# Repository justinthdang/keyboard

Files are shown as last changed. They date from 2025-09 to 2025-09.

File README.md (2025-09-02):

# 60% Mechancial Keyboard PCB
This repository showcases a 61-switch mechanical keyboard PCB made in Altium Designer for DFM with JLCPCB. The board is powered by a Raspberry Pi RP2040 chip on a 6-layer SIG-GND-PWR-SIG-GND-SIG stack up and follows the standard [GH60](https://github.com/komar007/gh60) layout + sizing for modern 60% mechanical keyboard cases. It features per-key RGB LED lighting, hot-swap sockets for MX-style switches, USB-C power & ESD protection, as well as support for UART, SWD, and UF2 bootloading. 

## Schematic
### Main Components
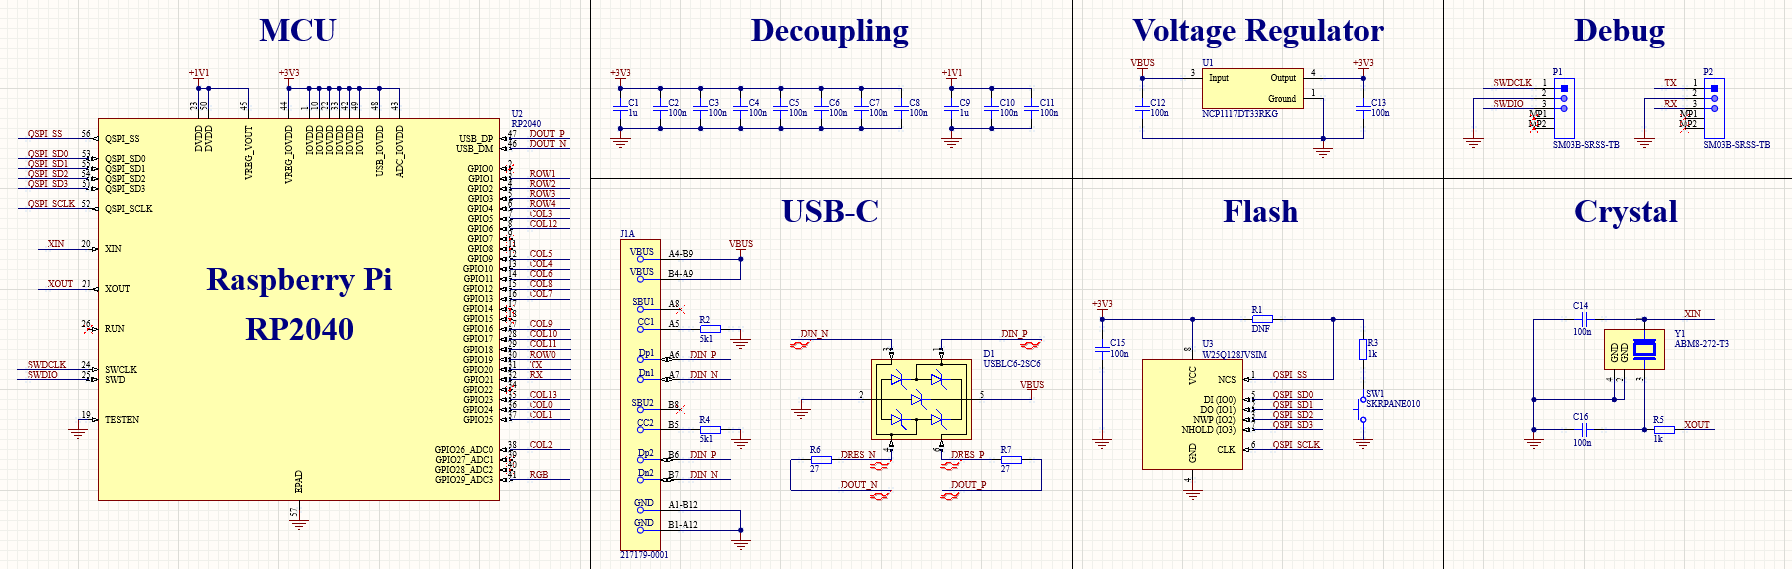
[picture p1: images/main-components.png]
Main Components Schematic

### Switch Matrix
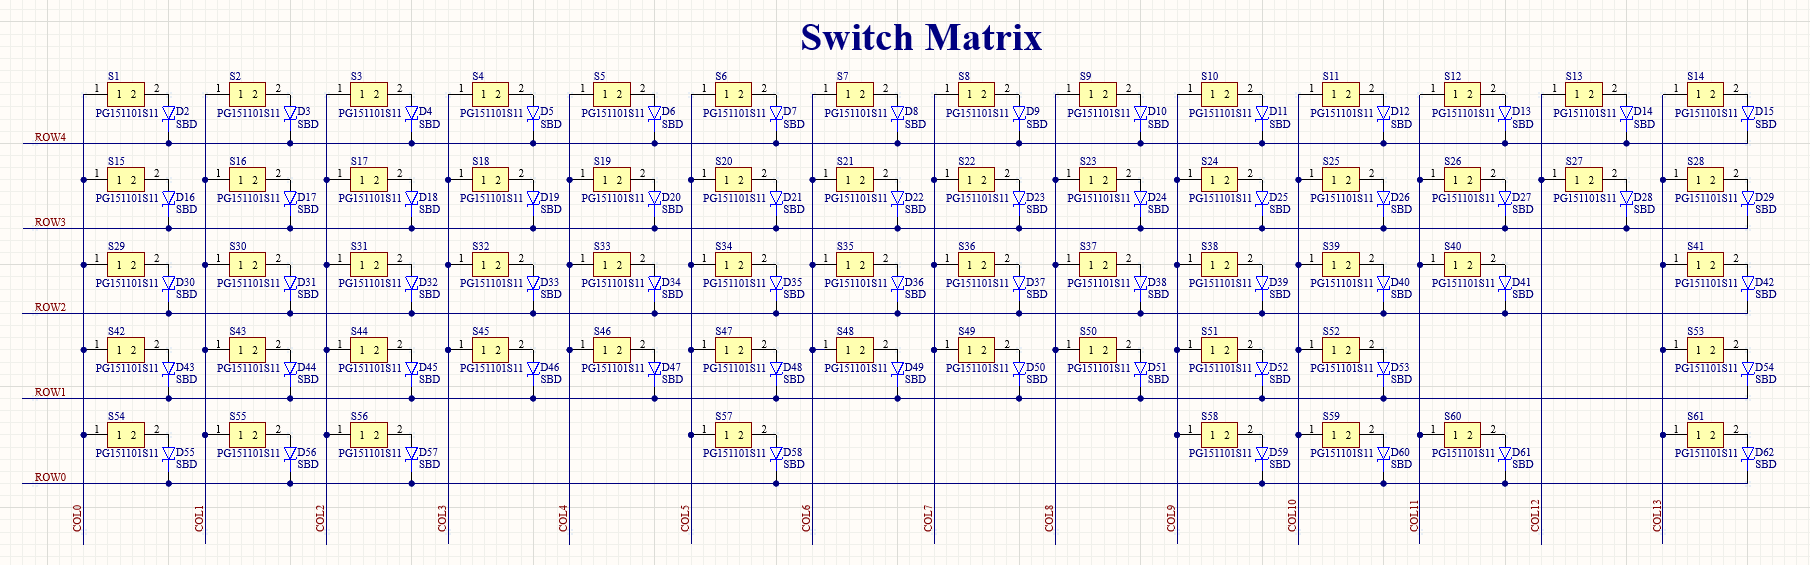
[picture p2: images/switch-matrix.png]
Switch Matrix Schematic

### RGB Matrix
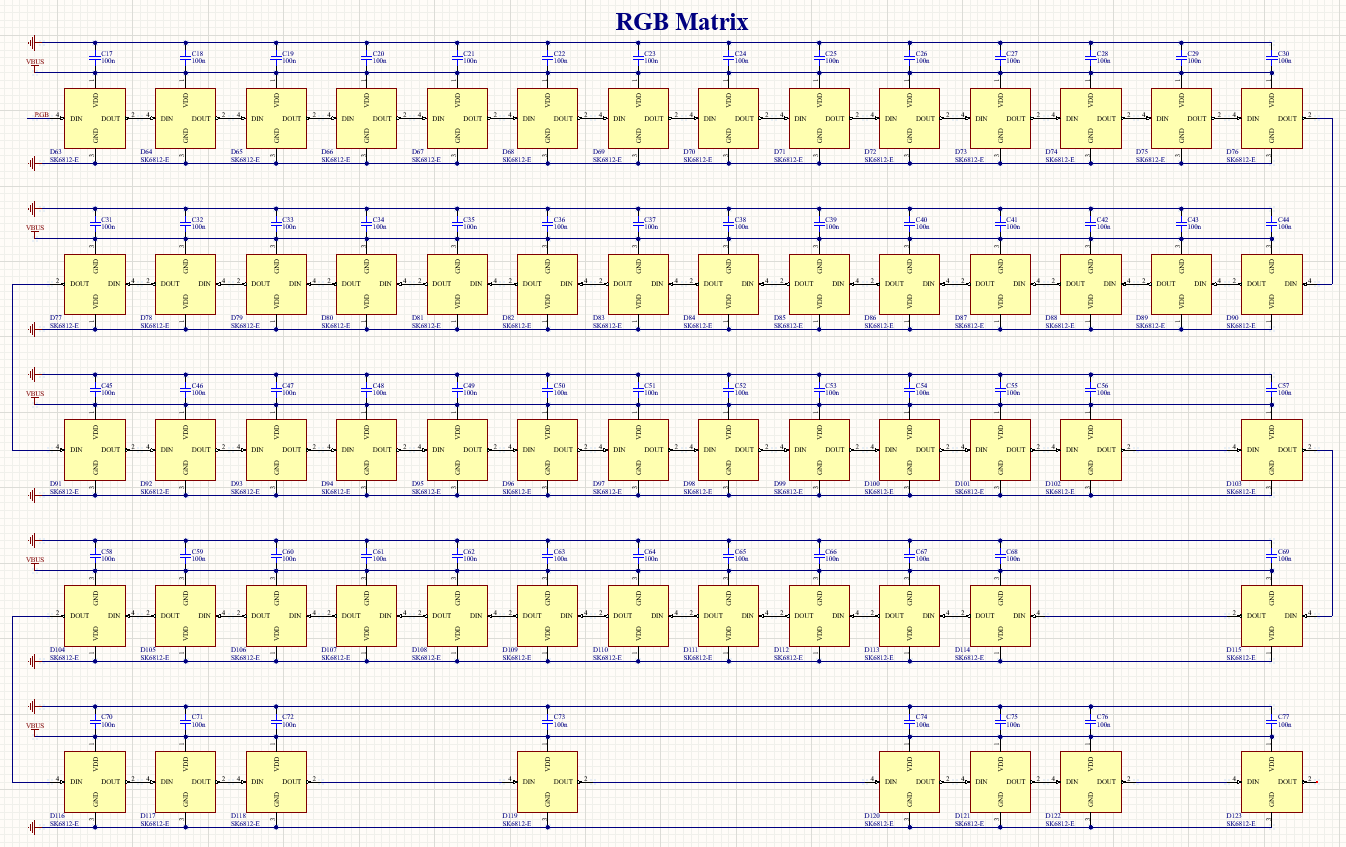
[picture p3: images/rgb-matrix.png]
RGB Matrix Schematic


## 2D View
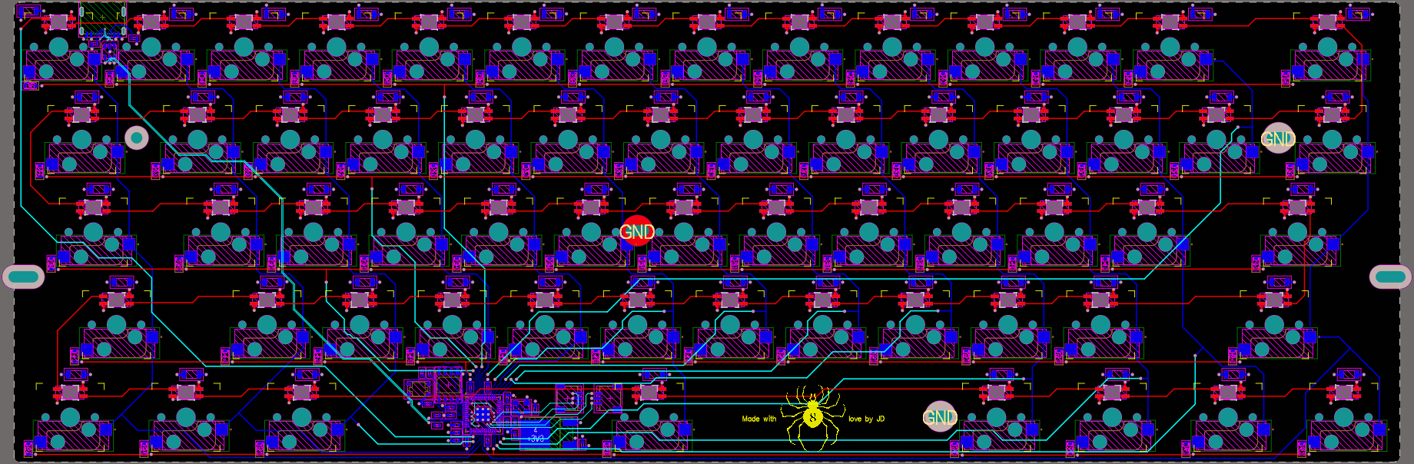
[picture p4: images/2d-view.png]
PCB 2D

**Note:** L2, L3, and L5 are hidden in this image since the polygon pours reduce the visibility of the traces/routing.

## 3D View
### Front
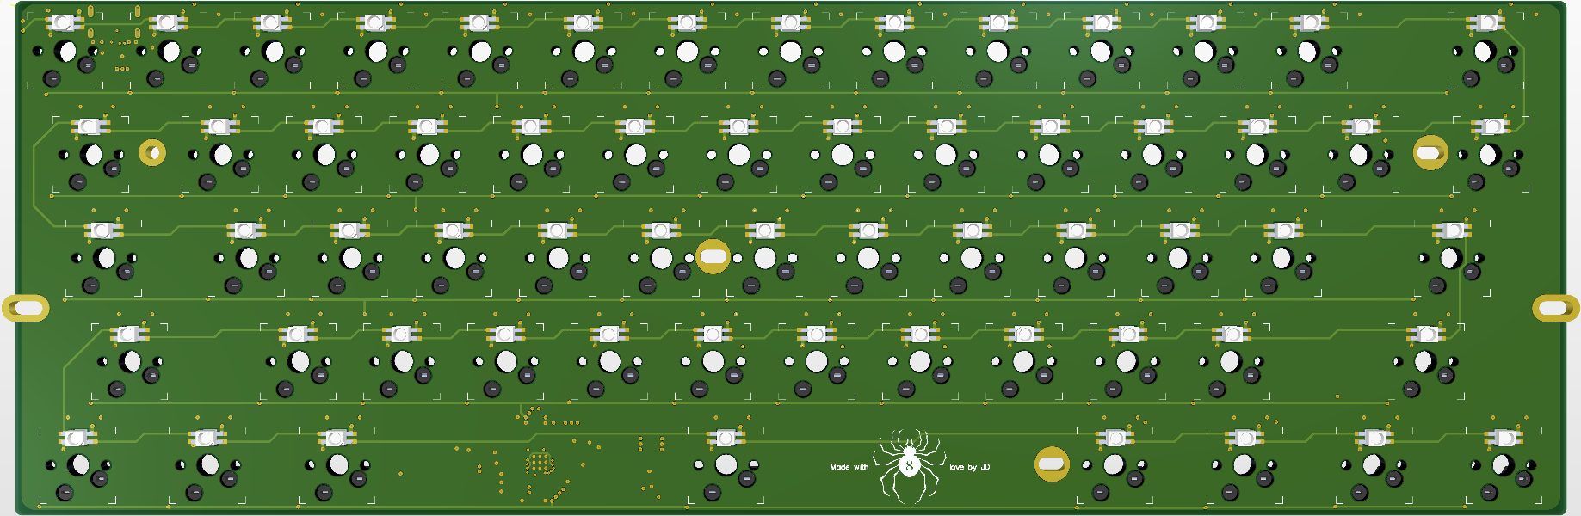
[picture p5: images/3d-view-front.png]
3D View Front

### Back
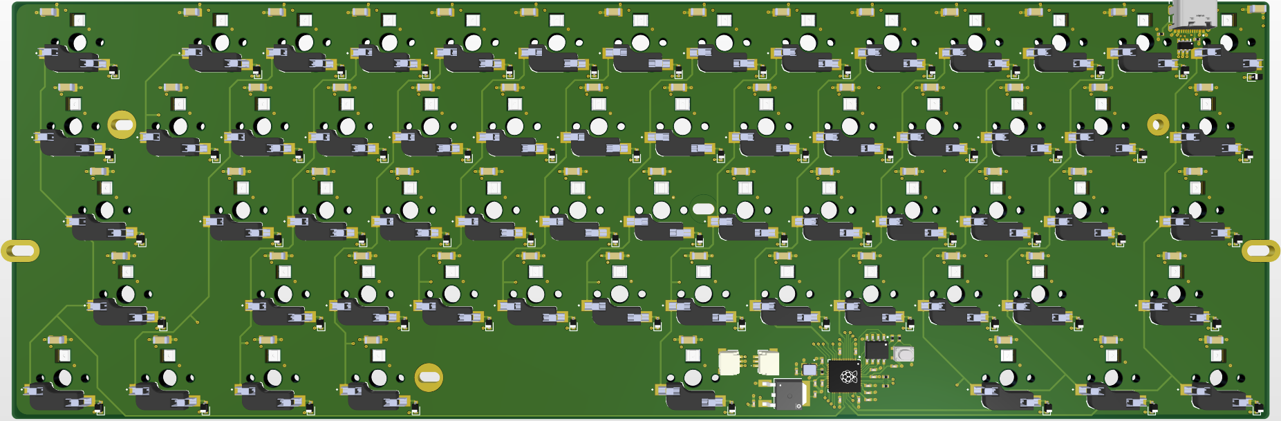
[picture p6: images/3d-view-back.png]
3D View Back


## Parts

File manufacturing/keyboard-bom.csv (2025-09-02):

Comment | Description | Designator | Footprint | LibRef | Quantity | LCSC Part #
1u | Capacitor SMD 0402 | C1, C9 | CAP_0402 | CAP_0402 | 2 | C14445
100n | Capacitor SMD 0402 | C2, C3, C4, C5, C6, C7, C8, C10, C11, C12, C13, C14, C15, C16 | CAP_0402 | CAP_0402 | 14 | C1525
100n | Capacitor SMD 1206 | C17, C18, C19, C20, C21, C22, C23, C24, C25, C26, C27, C28, C29, C30, C31, C32, C33, C34, C35, C36, C37, C38, C39, C40, C41, C42, C43, C44, C45, C46, C47, C48, C49, C50, C51, C52, C53, C54, C55, C56, C57, C58, C59, C60, C61, C62, C63, C64, C65, C66, C67, C68, C69, C70, C71, C72, C73, C74, C75, C76, C77 | CAP_1206 | CAP_1206 | 61 | C1945
USBLC6-2SC6 | Low-Capacitance ESD Protection USB | D1 | SOT-23-6 | USBLC6-2SC6 | 1 | C7519
SBD | Diode Schottky SMD SOD-323 | D2, D3, D4, D5, D6, D7, D8, D9, D10, D11, D12, D13, D14, D15, D16, D17, D18, D19, D20, D21, D22, D23, D24, D25, D26, D27, D28, D29, D30, D31, D32, D33, D34, D35, D36, D37, D38, D39, D40, D41, D42, D43, D44, D45, D46, D47, D48, D49, D50, D51, D52, D53, D54, D55, D56, D57, D58, D59, D60, D61, D62 | SOD-323 | D_SCHOTTKY_SOD_323 | 61 | C191023
SK6812-E | SK6812MINI-E is a smart LED control circuit and light emitting circuit in one controlled LED source, which has the shape of a 3528 LED chip. | D63, D64, D65, D66, D67, D68, D69, D70, D71, D72, D73, D74, D75, D76, D77, D78, D79, D80, D81, D82, D83, D84, D85, D86, D87, D88, D89, D90, D91, D92, D93, D94, D95, D96, D97, D98, D99, D100, D101, D102, D103, D104, D105, D106, D107, D108, D109, D110, D111, D112, D113, D114, D115, D116, D117, D118, D119, D120, D121, D122, D123 | LED_SK6812-E | SK6812-E | 61 | C5149201
217179-0001 | CONN RCP USB2.0 TYP C 24P SMD RA | J1 | FP-2171790001-MFG | CMP-04767-000028-2 | 1 | C3197684
DNF | Male Header, Pitch 1 mm, 1 x 3 Position, Height 2.9 mm, -25 to 85 degC, RoHS, Tape and Reel | P1, P2 | JST-SM03B-SRSS-TB_V | CMP-2000-07077-1 | 2
DNF | Resistor SMD 0402 | R1 | RES_0402 | RES_0402 | 1
5k1 | Resistor SMD 0402 | R2, R4 | RES_0402 | RES_0402 | 2 | C25905
1k | Resistor SMD 0402 | R3, R5 | RES_0402 | RES_0402 | 2 | C11702
27 | Resistor SMD 0402 | R6, R7 | RES_0402 | RES_0402 | 2 | C174257
PG151101S11 | Kailh Hotswap MX Socket | S1, S2, S3, S4, S5, S6, S7, S8, S9, S10, S11, S12, S13, S14, S15, S16, S17, S18, S19, S20, S21, S22, S23, S24, S25, S26, S27, S28, S29, S30, S31, S32, S33, S34, S35, S36, S37, S38, S39, S40, S41, S42, S43, S44, S45, S46, S47, S48, S49, S50, S51, S52, S53, S54, S55, S56, S57, S58, S59, S60, S61 | SW_PG151101S11 | PG151101S11 | 61 | C41430893
SKRPANE010 | Tactile Switch SMD SPST | SW1 | SKRPANE010 | SKRPANE010 | 1 | C470426
NCP1117DT33RKG | IC REG LINEAR 3.3V 1A DPAK-3 | U1 | FP-369C-MFG | CMP-07128-000036-1 | 1 | C88234
RP2040 | 32-Bit Dual-Core ARM Cortex-M0+ Microcontroller | U2 | QFN-56-EP | RP2040 | 1 | C2040
W25Q128JVSIM | 128M-BIT SERIAL FLASH MEMORY WITH DUAL/QUAD SPI & QPI & DTR SOIC-8 | U3 | SOIC-8 | W25Q128JVSIM | 1 | C2613930
ABM8-272-T3 | 12 MHz ±30ppm Crystal 10pF 50 Ohms 4-SMD, No Lead | Y1 | XTAL_ABM8-272-T3 | ABM8-272-T3 | 1 | C20625731
